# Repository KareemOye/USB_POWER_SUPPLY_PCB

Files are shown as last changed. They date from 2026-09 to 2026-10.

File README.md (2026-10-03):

# USB Power Supply (12 V to 5 V)
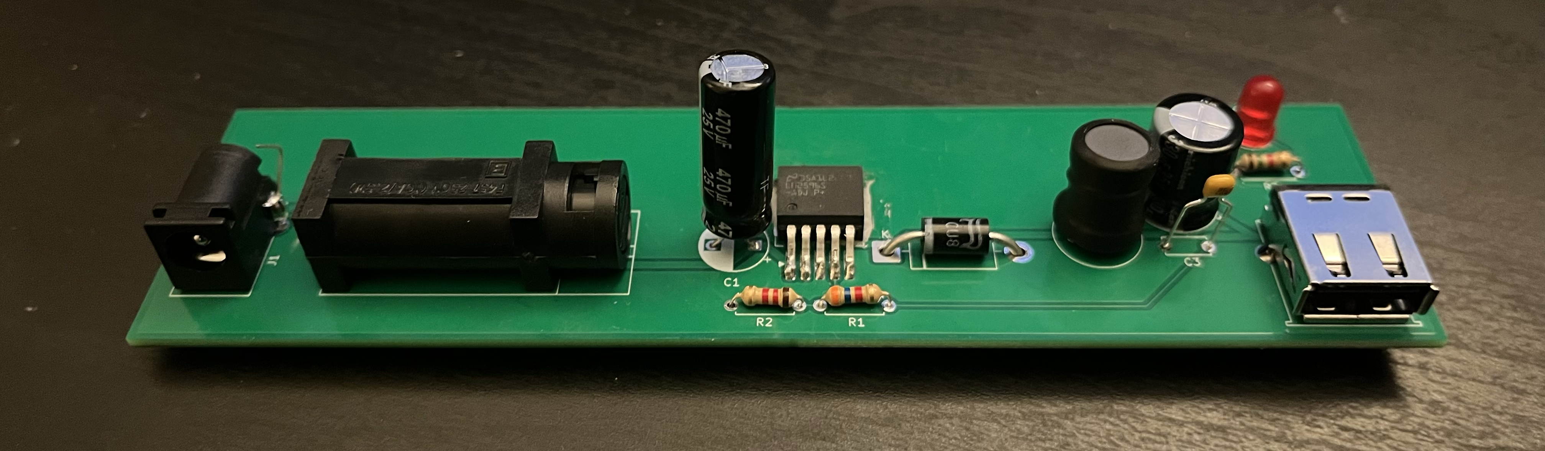
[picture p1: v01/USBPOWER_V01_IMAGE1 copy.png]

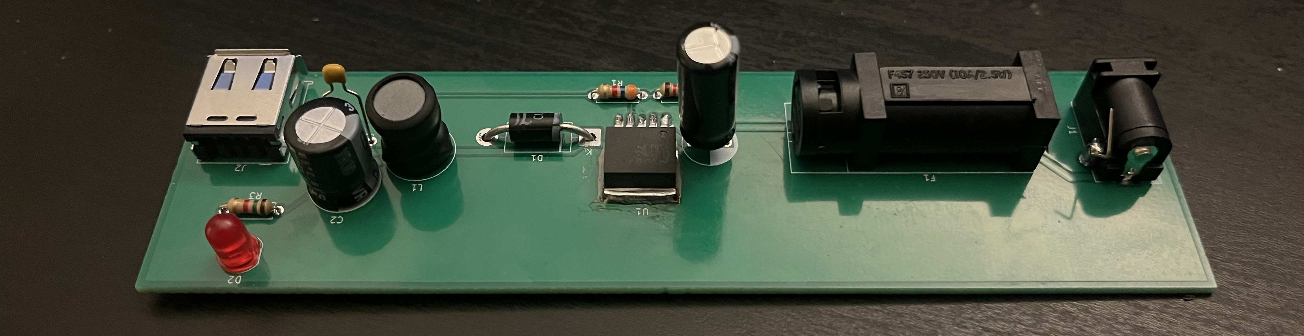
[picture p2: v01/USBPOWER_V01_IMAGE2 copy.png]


I started this project shortly before beginning my electrical engineering
studies, as a way to learn electronics and circuit design through hands-on
experience. A 12 V to 5 V USB step-down supply seemed like a good first PCB
build, and having now designed and assembled it, I think that was the right
call.

 ## Design

I went with a buck converter rather than a linear regulator, since dropping
12 V to 5 V linearly would waste a very significant amount of power as heat. 
The LM2596S-ADJ handles the switching, and a 1N5822 Schottky diode carries the 
inductor current while the internal switch is off. The feedback pin regulates 
to 1.23 V, so the 3.6 kΩ and 1.2 kΩ divider sets the output to about 4.9 V, 
and a 47 µH inductor smooths the current.

On the input side, a 1.6 A slow-blow fuse protects against shorts and a
470 µF capacitor supplies the pulsed current the converter draws when
switching. At the output, a 330 µF electrolytic and a 100 nF ceramic reduce
ripple, the USB D+ and D- lines are shorted so devices recognise it as a
charger, and a power LED shows when the output is live.

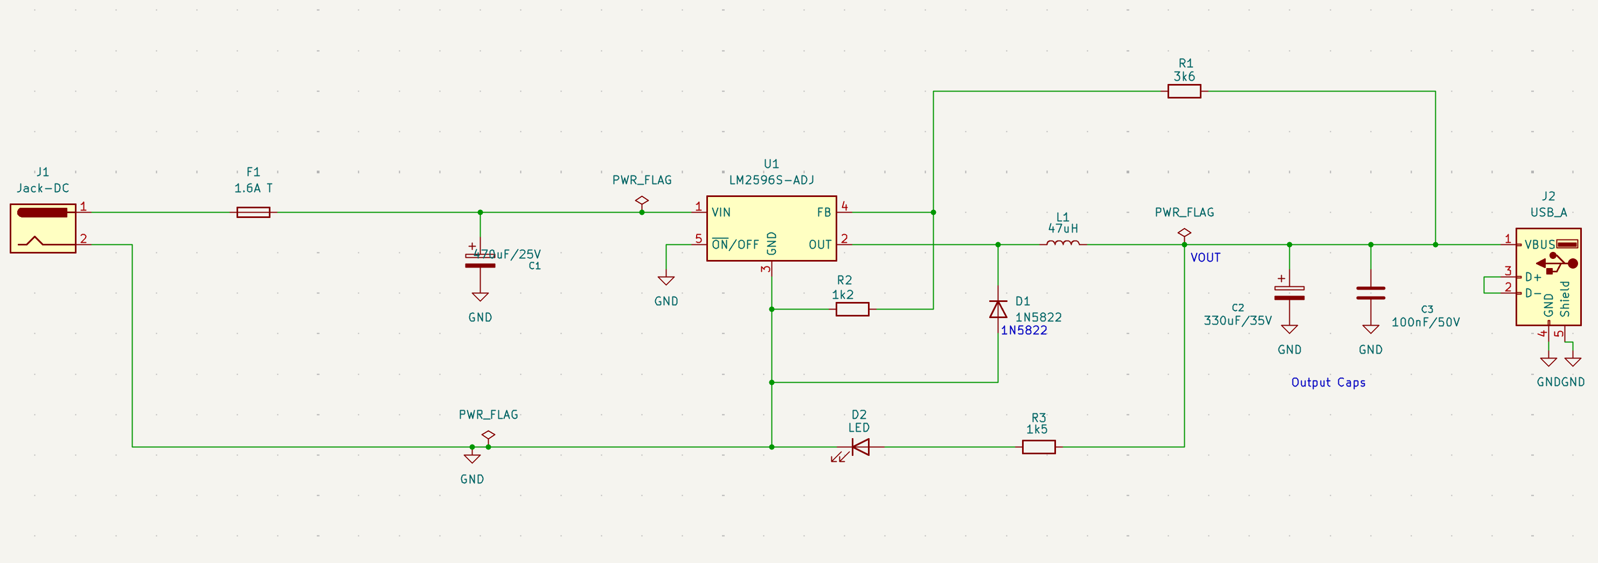
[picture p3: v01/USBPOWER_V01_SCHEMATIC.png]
Schematic


## PCB

The board is a 2-layer approximately 145 × 38 mm design routed in
KiCad, with one SMD component and the rest being through-hole and a ground 
pour on the bottom layer. I kept the input capacitor, LM2596, diode and
inductor close together to keep the high-current switching loop small, which
reduces noise and ringing.

The feedback trace is routed away from the inductor and switching node so
the output regulation isn't disturbed, and the power traces are widened to
1 mm to handle the current. 

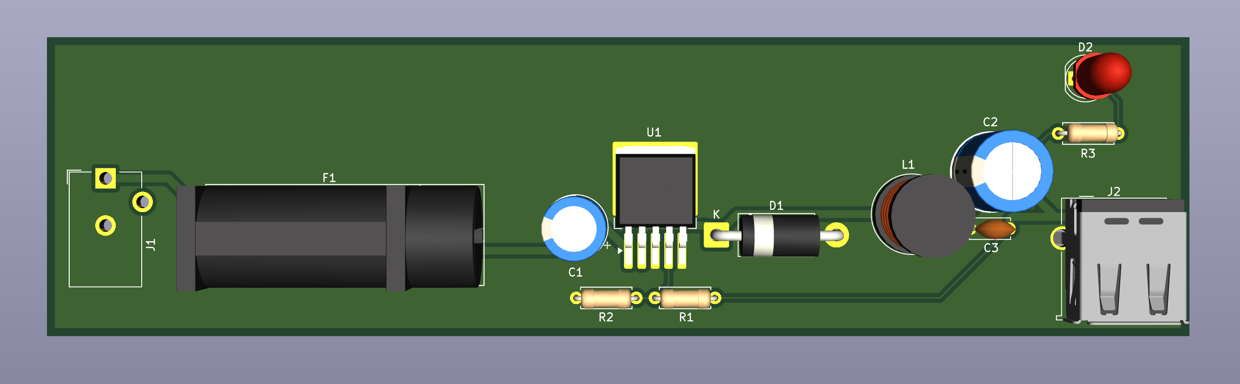
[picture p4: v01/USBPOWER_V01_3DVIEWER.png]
3D render of the board


## Testing & Measurement

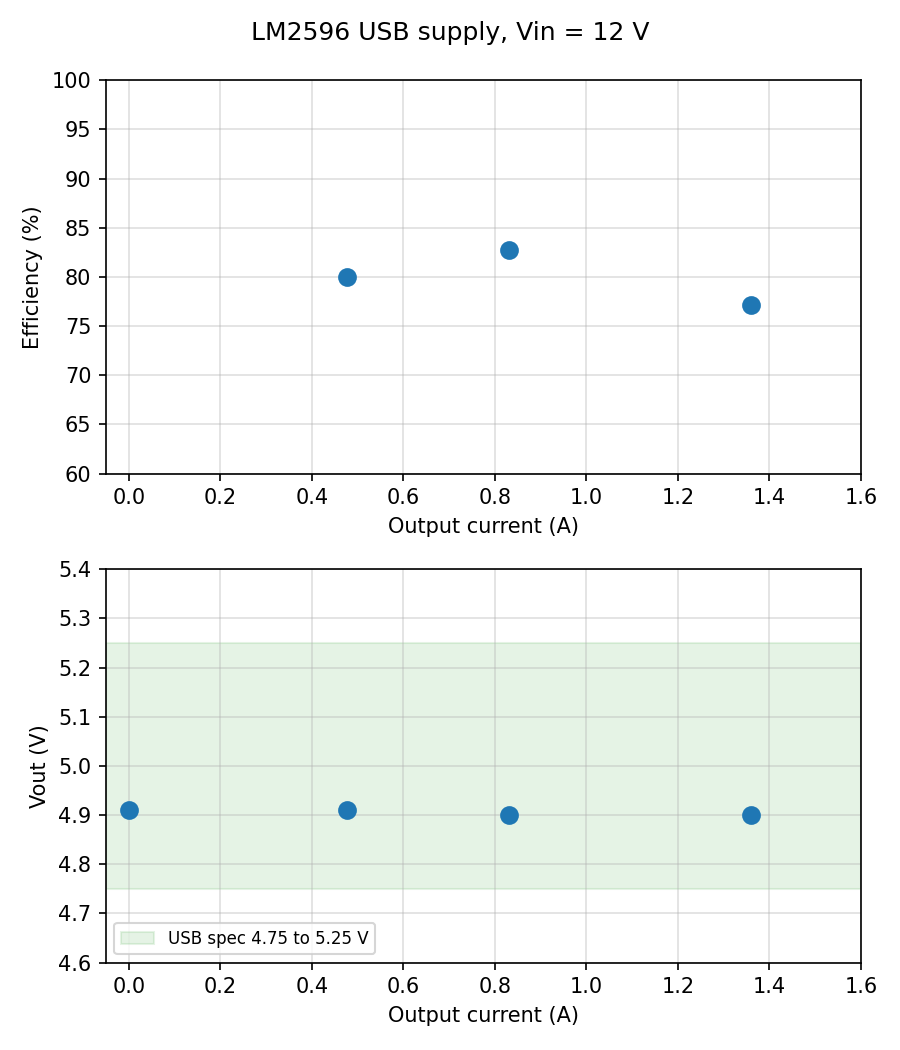
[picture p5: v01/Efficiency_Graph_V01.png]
Efficiency and load regulation


Measured at Vin = 12 V with resistive loads (10.3 Ω, 5.9 Ω, 3.6 Ω), Vout taken at the
USB connector and input power from the bench supply readout. 

Efficiency is about 80 to 83 % up to 0.8 A and drops to about 77 % at 1.36 A, where
the board runs very hot (around 2 W of losses). Vout stays between 4.90 and 4.91 V
from no load to 1.36 A, well inside the USB spec. 

## What I learned

This was my first time taking a circuit all the way from schematic to a
working board. I learned how a buck converter works in practice, how to read
a datasheet to choose supporting components, and how much layout matters
for switching circuits. The build also taught me the practical side:
footprints, ordering parts and hand soldering.

Looking back, the layout is quite spread out and wasn't optimized for size or 
performance. The next revision applies what I learned here, with SMD components, a
tighter layout and a 4-layer stackup, bringing the board down from 145 × 38 mm
to 41 × 37 mm.

## Next revision (in progress)

I am making a second board with the same function but a far more compact 4-layer
design, 41 × 37 mm, built around the TI LMR33630. Unlike the LM2596, it's
a synchronous converter with an integrated low-side switch, so the Schottky
diode is gone and efficiency should improve, especially at higher loads. It
also switches at 400 kHz instead of 150 kHz, which allows a smaller 10 µH
inductor and ceramic output capacitors in place of the large electrolytic.
The divider is now 100 kΩ / 24.9 kΩ against a 1.0 V reference, which would 
make the output 5.02&nbsp;V according to calculation.

The board has already been designed and routed in KiCad, so the remaining
steps are ordering parts, assembly and testing.

Once the second board is assembled and ready I'll compare the two boards on 
efficiency, output ripple and temperature.

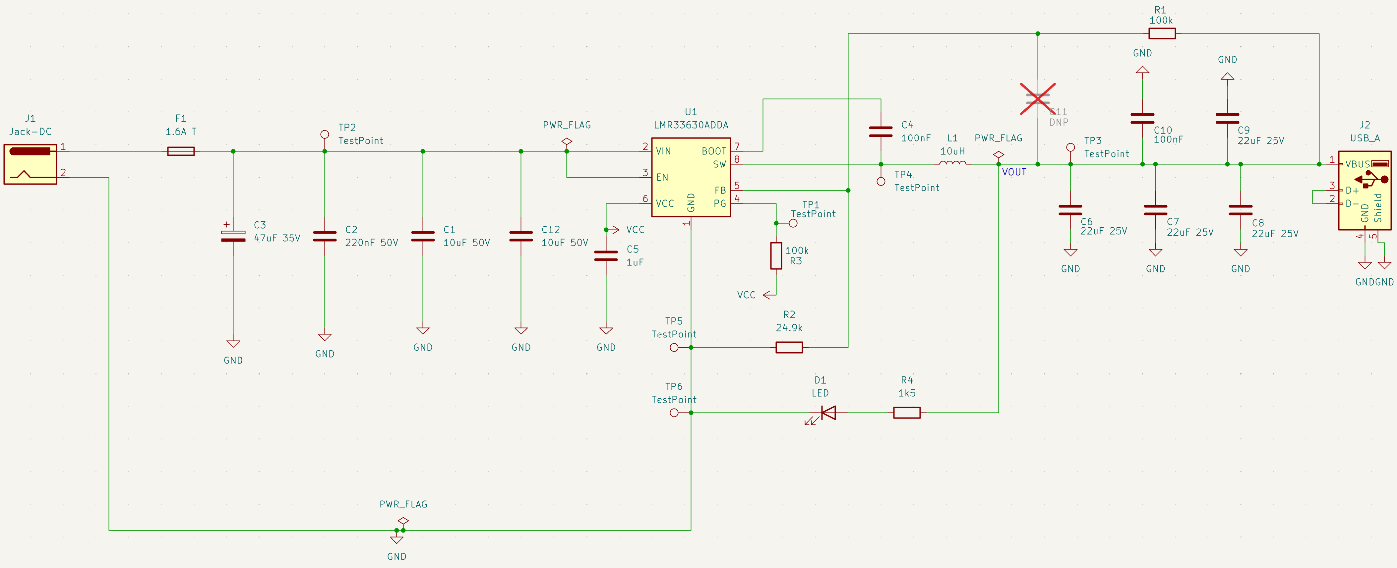
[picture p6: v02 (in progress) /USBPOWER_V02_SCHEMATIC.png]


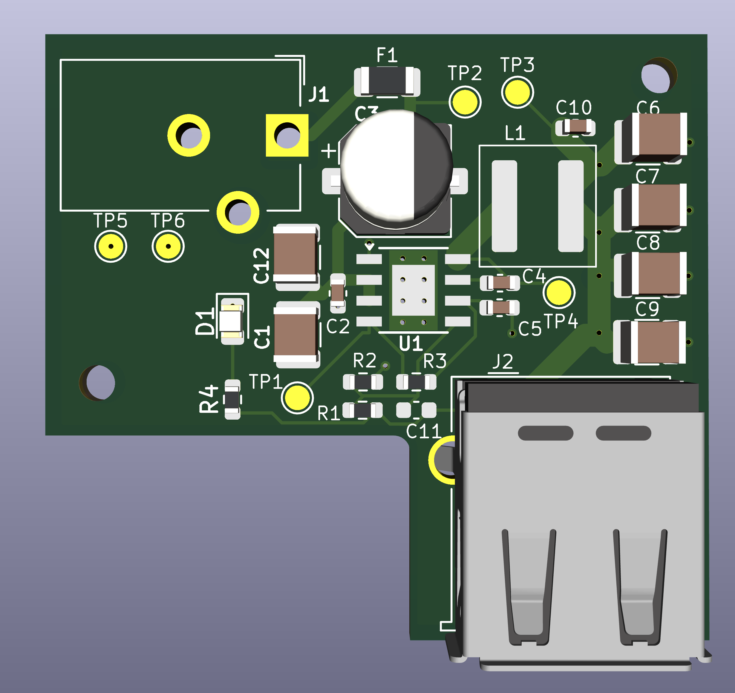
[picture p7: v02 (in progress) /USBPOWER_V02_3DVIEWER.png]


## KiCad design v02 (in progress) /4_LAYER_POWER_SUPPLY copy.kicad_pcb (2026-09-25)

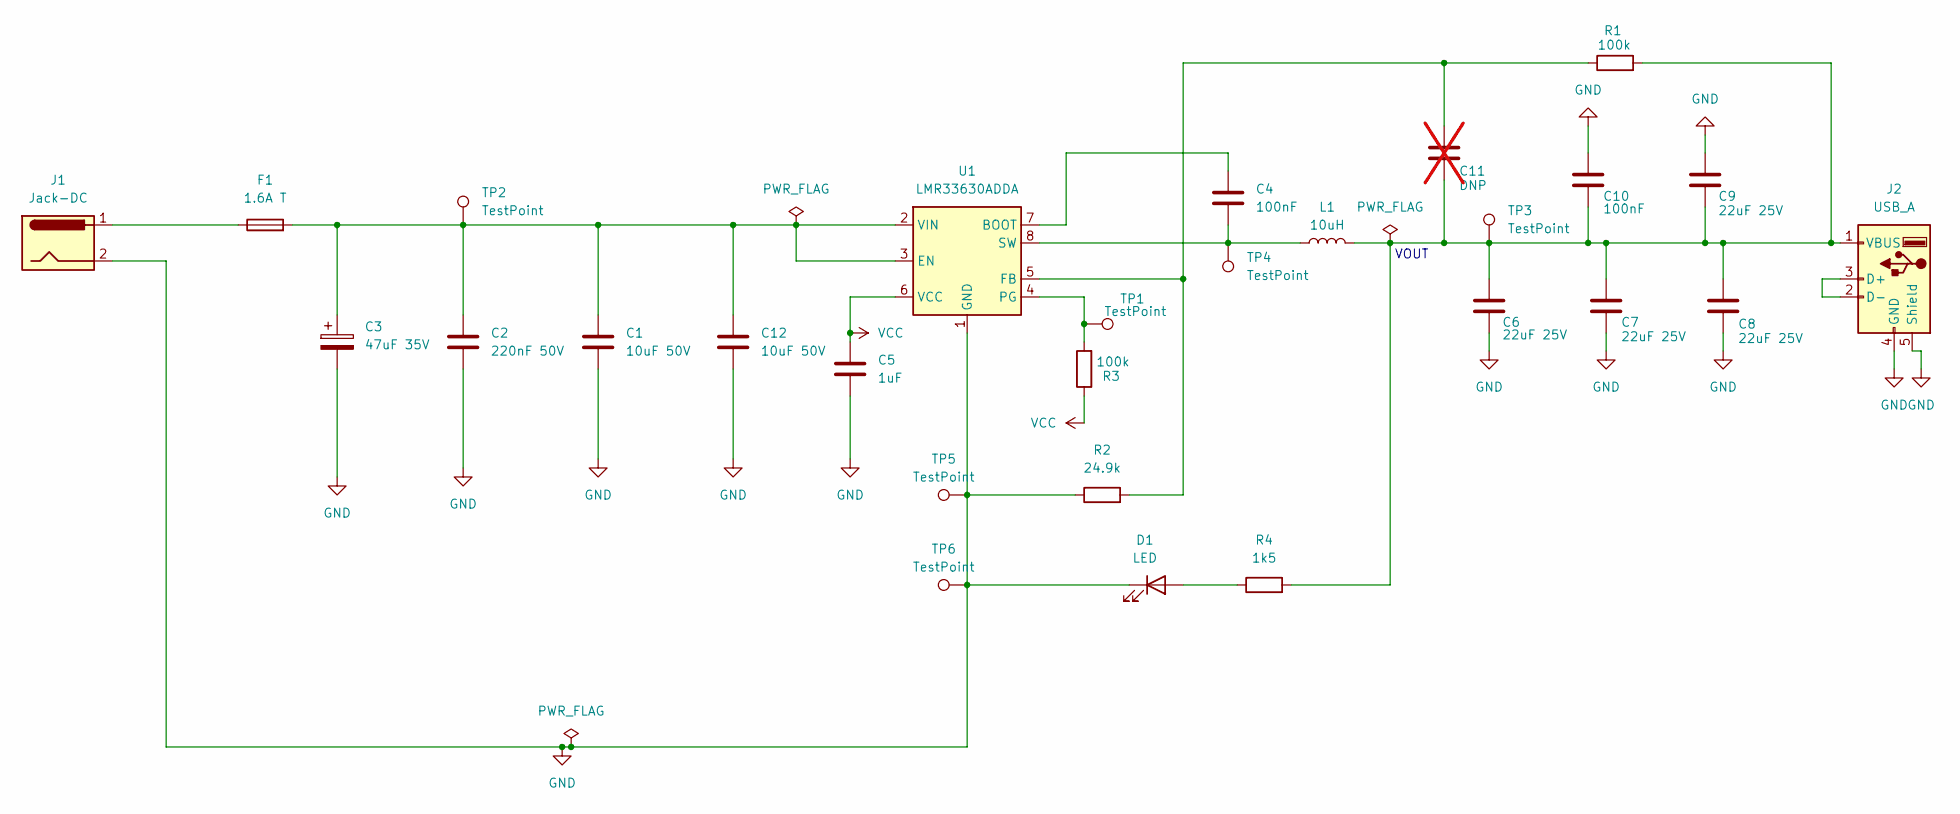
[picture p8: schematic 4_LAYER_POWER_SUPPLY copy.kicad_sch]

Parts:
C1, C12: 10uF 50V; C_1210_3225Metric
C2: 220nF 50V; C_0603_1608Metric
C3: 47uF 35V; CP_Elec_6.3x5.8
C4, C10: 100nF; C_0603_1608Metric
C5: 1uF; C_0603_1608Metric
C6, C7, C8, C9: 22uF 25V; C_1210_3225Metric
C11: DNP; C_0603_1608Metric; not fitted
D1: LED; LED_0805_2012Metric
F1: 1.6A T; Fuse_1206_3216Metric
J1: Jack-DC; BarrelJack_CUI_PJ-102AH_Horizontal
J2: USB_A; USB_A_Molex_67643_Horizontal
L1: 10uH; L_Eaton_EXL1V0606
R1, R3: 100k; R_0603_1608Metric
R2: 24.9k; R_0603_1608Metric
R4: 1k5; R_0603_1608Metric
TP1, TP2, TP3, TP4, TP5, TP6: TestPoint; TestPoint_Pad_D1.5mm
U1: LMR33630ADDA; Texas_HSOP-8-1EP_3.9x4.9mm_P1.27mm_ThermalVias

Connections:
GND: C1.2, C2.2, C3.2, C5.2, C6.2, C7.2, C8.2, C9.1, C10.1, C12.2, D1.1 (K), J1.2, J2.4 (GND), J2.5 (Shield), R2.1, TP5.1, TP6.1, U1.1 (GND), U1.9 (GND)
unnamed: D1.2 (A), R4.1
unnamed: F1.1, J1.1
unnamed: J2.2 (D-), J2.3 (D+)
unnamed: C6.1, C7.1, C8.1, C9.2, C10.2, C11.2, J2.1 (VBUS), L1.2, R1.2, R4.2, TP3.1
unnamed: C4.1, U1.7 (BOOT)
unnamed: C1.1, C2.1, C3.1, C12.1, F1.2, TP2.1, U1.2 (VIN), U1.3 (EN)
unnamed: C11.1, R1.1, R2.2, U1.5 (FB)
unnamed: R3.2, TP1.1, U1.4 (PG)
unnamed: C4.2, L1.1, TP4.1, U1.8 (SW)
VCC: C5.1, R3.1, U1.6 (VCC)

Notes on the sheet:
VOUT

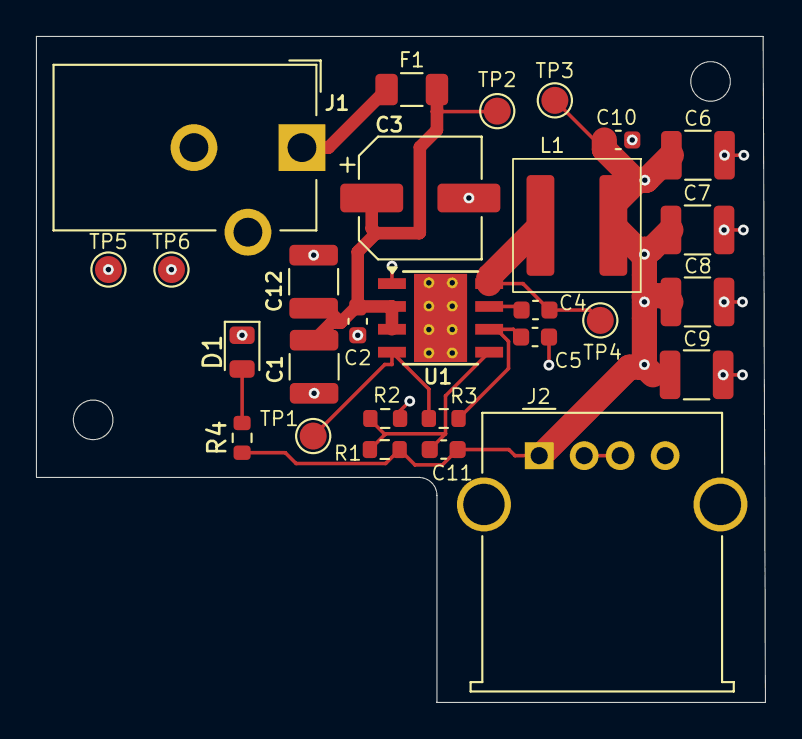
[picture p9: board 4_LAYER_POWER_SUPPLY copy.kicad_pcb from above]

Board: 4 copper layers, 40.5 x 37.0 mm, 28 parts (0 on the bottom side), 11 nets.

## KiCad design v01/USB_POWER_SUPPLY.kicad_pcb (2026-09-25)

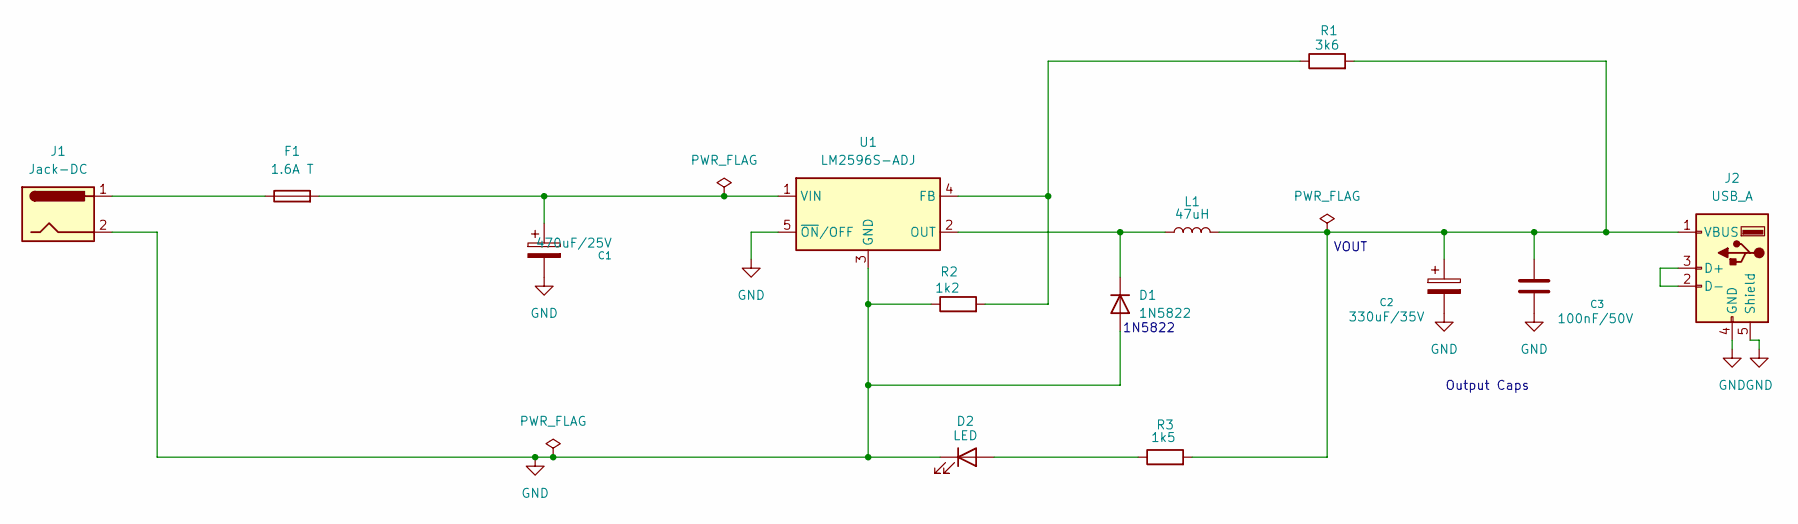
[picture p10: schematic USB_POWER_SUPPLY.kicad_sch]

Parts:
C1: 470uF/25V; CP_Radial_D8.0mm_P5.00mm
C2: 330uF/35V; CP_Radial_D10.0mm_P5.00mm
C3: 100nF/50V; C_Disc_D5.0mm_W2.5mm_P5.00mm
D1: 1N5822; D_DO-201AD_P15.24mm_Horizontal
D2: LED; LED_D5.0mm
F1: 1.6A T; Fuseholder_Cylinder-5x20mm_Bulgin_FX0457_Horizontal_Closed
J1: Jack-DC; BarrelJack_CUI_PJ-102AH_Horizontal
J2: USB_A; USB_A_Molex_67643_Horizontal
L1: 47uH; L_Radial_D10.0mm_P5.00mm_Fastron_07P
R1: 3k6; R_Axial_DIN0207_L6.3mm_D2.5mm_P7.62mm_Horizontal
R2: 1k2; R_Axial_DIN0207_L6.3mm_D2.5mm_P7.62mm_Horizontal
R3: 1k5; R_Axial_DIN0207_L6.3mm_D2.5mm_P7.62mm_Horizontal
U1: LM2596S-ADJ; TO-263-5_TabPin3

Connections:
GND: C1.2, C2.2, C3.1, D1.2 (A), D2.1 (K), J1.2, J2.4 (GND), J2.5 (Shield), R2.1, U1.3 (GND), U1.5 (~ON/OFF)
unnamed: D1.1 (K), L1.1, U1.2 (OUT)
unnamed: D2.2 (A), R3.1
unnamed: F1.1, J1.1
unnamed: J2.2 (D-), J2.3 (D+)
unnamed: C2.1, C3.2, J2.1 (VBUS), L1.2, R1.2, R3.2
unnamed: R1.1, R2.2, U1.4 (FB)
unnamed: C1.1, F1.2, U1.1 (VIN)

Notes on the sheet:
VOUT
Output Caps
1N5822

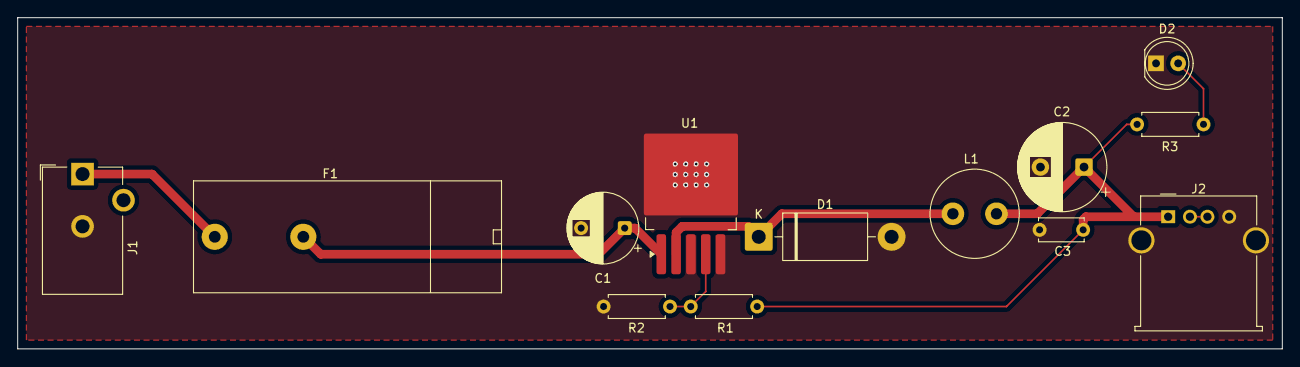
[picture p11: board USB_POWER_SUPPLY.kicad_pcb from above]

Board: 2 copper layers, 145.1 x 38.0 mm, 13 parts (0 on the bottom side), 8 nets.

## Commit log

2026-09-25 Rename USB_POWER_SUPPLY.kicad_pcb to V1 /USB_POWER_SUPPLY.kicad_pcb
    [USB_POWER_SUPPLY.kicad_pcb]
2026-09-25 Rename USB_POWER_SUPPLY.kicad_sch to v1 LM2596 board, built and tested /USB_POWER_SUPPLY.kicad_sch
    [USB_POWER_SUPPLY.kicad_sch]
2026-09-25 Rename USBPOWER_V01_IMAGE.pdf to V01 LM2596 board, built and tested /USBPOWER_V01_IMAGE.pdf
2026-09-25 Rename USBPOWER_V01_SCHEMATIC.pdf to V01 LM2596 board, built and tested /USBPOWER_V01_SCHEMATIC.pdf
2026-09-25 Rename USB_POWER_SUPPLY.kicad_pro to V01 LM2596 board, built and tested /USB_POWER_SUPPLY.kicad_pro
2026-09-25 Rename 4_LAYER_POWER_SUPPLY copy.kicad_pcb to V02 LMR33630 board, in progress /4_LAYER_POWER_SUPPLY copy.kicad_pcb
    [4_LAYER_POWER_SUPPLY copy.kicad_pcb]
2026-09-25 Rename 4_LAYER_POWER_SUPPLY copy.kicad_pro to V02 LMR33630 board, in progress /4_LAYER_POWER_SUPPLY copy.kicad_pro
2026-09-25 Rename 4_LAYER_POWER_SUPPLY copy.kicad_sch to V02 LMR33630 board, in progress /4_LAYER_POWER_SUPPLY copy.kicad_sch
    [4_LAYER_POWER_SUPPLY copy.kicad_sch]
2026-09-25 Rename USBPOWER_V02_3DVIEW.png to V02 LMR33630 board, in progress /USBPOWER_V02_3DVIEW.png
2026-09-25 Rename USBPOWER_V02_SCHEMATIC.pdf to V02 LMR33630 board, in progress /USBPOWER_V02_SCHEMATIC.pdf
2026-09-25 Rename Folders
    [4_LAYER_POWER_SUPPLY copy.kicad_pcb, 4_LAYER_POWER_SUPPLY copy.kicad_sch, USB_POWER_SUPPLY.kicad_pcb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]
